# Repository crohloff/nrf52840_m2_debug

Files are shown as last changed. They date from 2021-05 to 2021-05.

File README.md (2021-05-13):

# nrf52840_m2_debug
Debug board for the M.2 module

## features
- access to all pins
- 4 buttons
- 4 LEDs
- USB-C connectivity
- TC2030 debug connector

## dimensions
- 60mm x 90mm

## board front
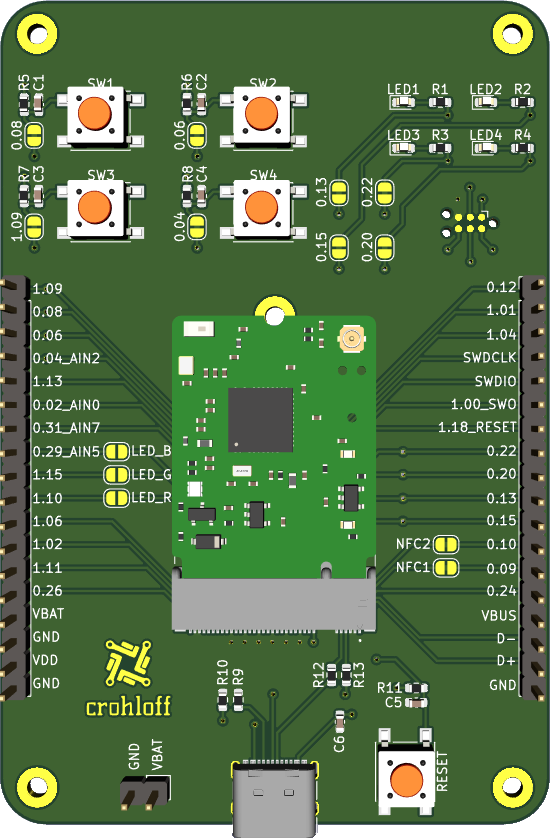
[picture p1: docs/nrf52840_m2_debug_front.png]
board front


## board back
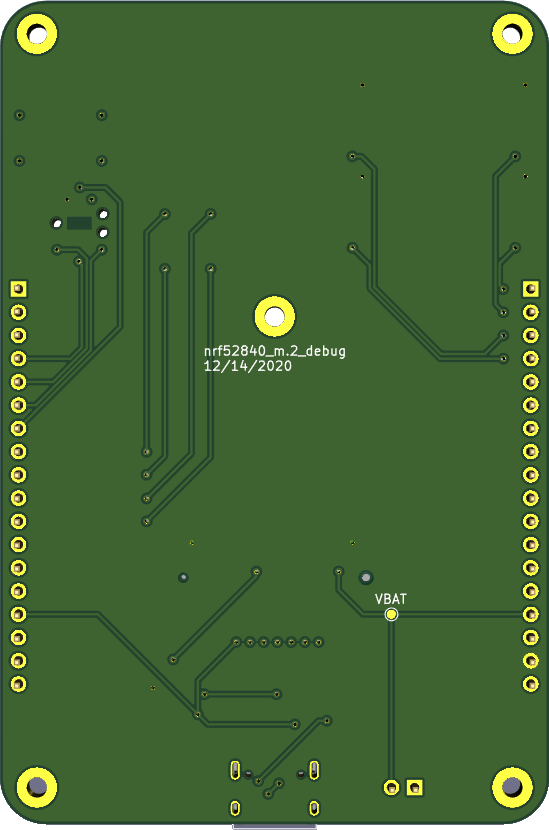
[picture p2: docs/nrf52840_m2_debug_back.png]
board back


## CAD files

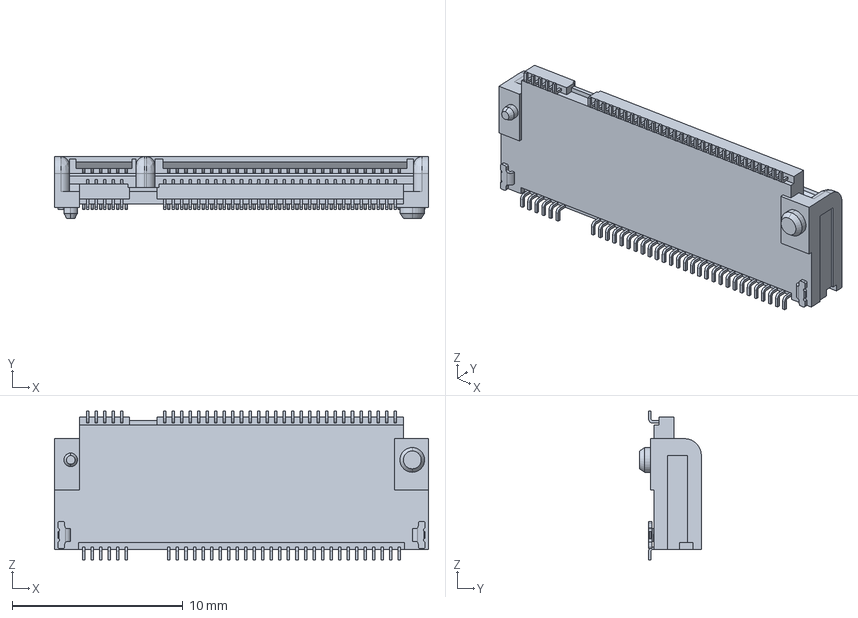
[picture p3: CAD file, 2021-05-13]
custom_3d/te_connectivity_121991190.stp
21.9 x 3.62 x 8.70 mm

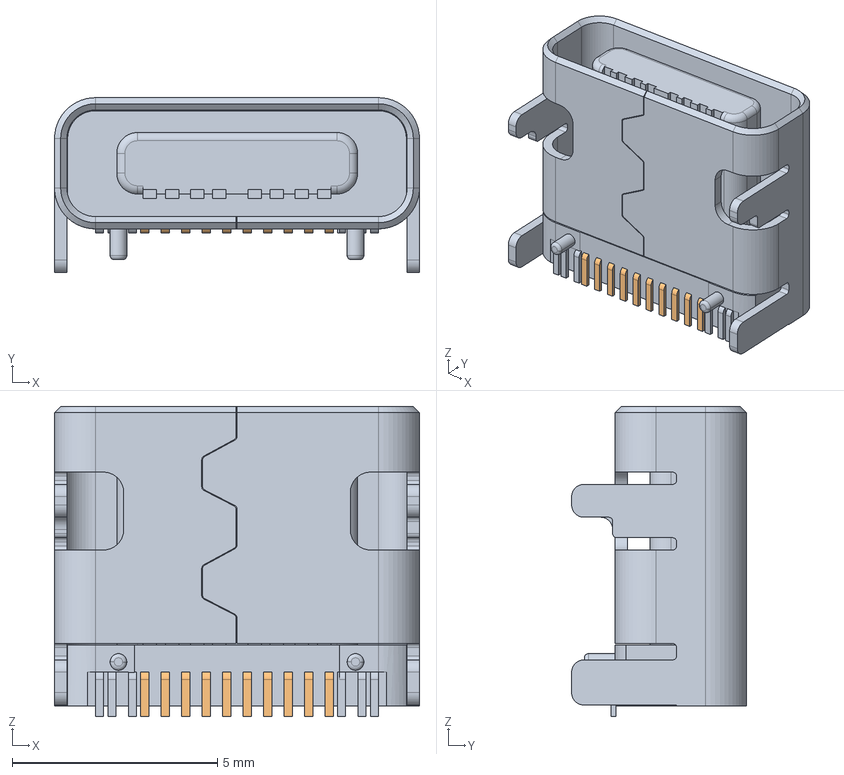
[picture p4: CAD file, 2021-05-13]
custom_3d/XKB_U262-16XN-4BVC11.stp
8.90 x 4.26 x 7.56 mm

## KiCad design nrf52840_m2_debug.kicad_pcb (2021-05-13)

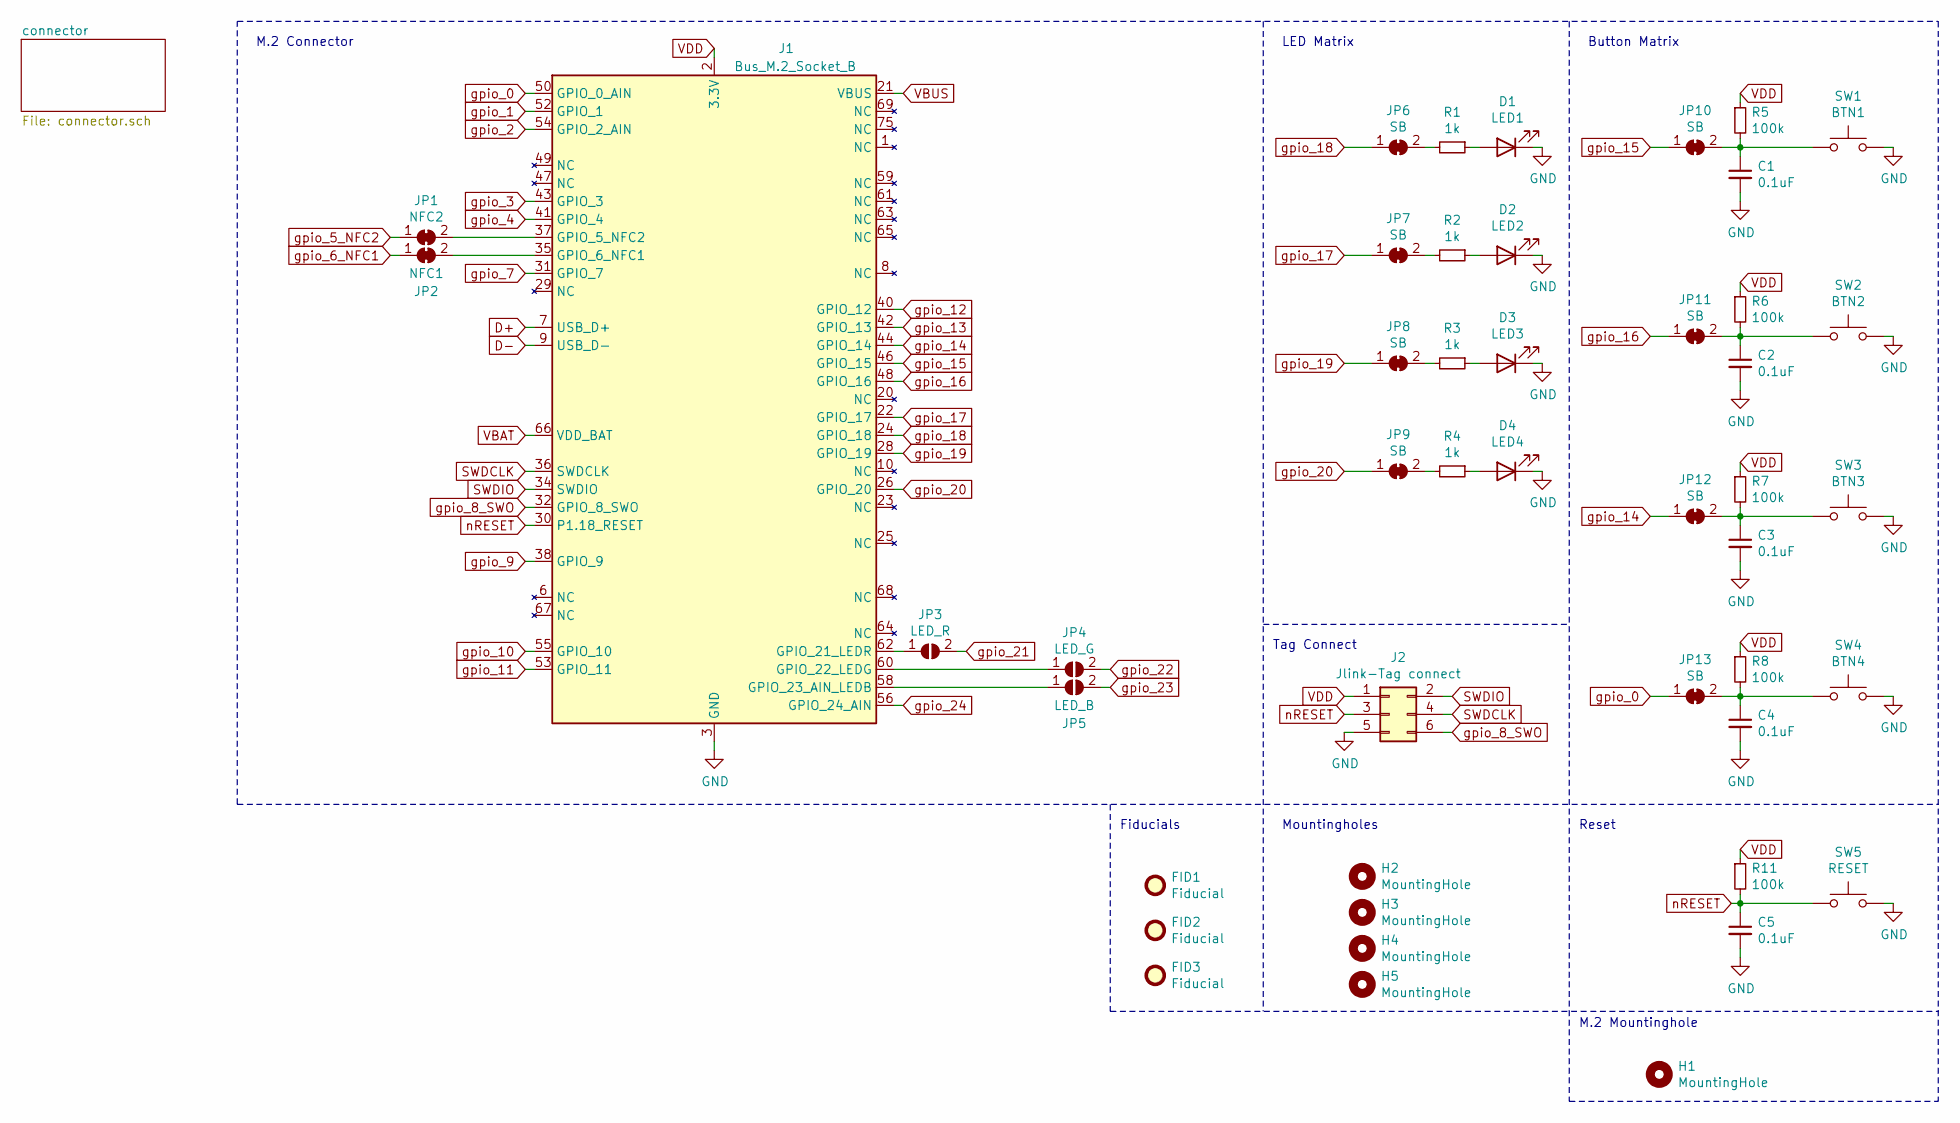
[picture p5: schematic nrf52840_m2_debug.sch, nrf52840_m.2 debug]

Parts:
C1, C2, C3, C4, C5: 0.1uF; C_0603_1608Metric; MFG P/N 063F104Z500CT; LCSC C83060
D1: LED1; LED_0603_1608Metric; MFG P/N LTST-C190KFKT; LCSC C157740
D2: LED2; LED_0603_1608Metric; MFG P/N LTST-C190KFKT; LCSC C157740
D3: LED3; LED_0603_1608Metric; MFG P/N LTST-C190KFKT; LCSC C157740
D4: LED4; LED_0603_1608Metric; MFG P/N LTST-C190KFKT; LCSC C157740
FID1, FID2, FID3: Fiducial; Fiducial_1mm_Mask2mm
H1, H2, H3, H4, H5: MountingHole; MountingHole_2.2mm_M2_Pad
J1: Bus_M.2_Socket_B; te_connectivity_121991190; MFG P/N 2199119; Mouser 571-1-2199119-0
J2: Jlink-Tag connect; Tag-Connect_TC2030-IDC-NL_2x03_P1.27mm_Vertical
JP1: NFC2; SolderJumper-2_P1.3mm_Bridged_RoundedPad1.0x1.5mm
JP2: NFC1; SolderJumper-2_P1.3mm_Bridged_RoundedPad1.0x1.5mm
JP3: LED_R; SolderJumper-2_P1.3mm_Open_RoundedPad1.0x1.5mm
JP4: LED_G; SolderJumper-2_P1.3mm_Open_RoundedPad1.0x1.5mm
JP5: LED_B; SolderJumper-2_P1.3mm_Open_RoundedPad1.0x1.5mm
JP6, JP7, JP8, JP9, JP10, JP11, JP12, JP13: SB; SolderJumper-2_P1.3mm_Bridged_RoundedPad1.0x1.5mm
R1, R2, R3, R4: 1k; R_0603_1608Metric; MFG P/N RC0603JR-071KL; LCSC C14676
R5, R6, R7, R8, R11: 100k; R_0603_1608Metric; MFG P/N RC0603JR-07100KL; LCSC C100048
SW1: BTN1; SW_SPST_PTS645; MFG P/N PTS645SH43SMTR92LFS; LCSC C285463
SW2: BTN2; SW_SPST_PTS645; MFG P/N PTS645SH43SMTR92LFS; LCSC C285463
SW3: BTN3; SW_SPST_PTS645; MFG P/N PTS645SH43SMTR92LFS; LCSC C285463
SW4: BTN4; SW_SPST_PTS645; MFG P/N PTS645SH43SMTR92LFS; LCSC C285463
SW5: RESET; SW_SPST_PTS645; MFG P/N PTS645SH43SMTR92LFS; LCSC C285463

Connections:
D+: J1.7 (USB_D+); also elsewhere on the board
D-: J1.9 (USB_D-); also elsewhere on the board
GND: C1.2, C2.2, C3.2, C4.2, C5.2, D1.1 (K), D2.1 (K), D3.1 (K), D4.1 (K), J1.3 (GND), J1.5 (GND), J1.11 (GND), J1.27 (GND), J1.33 (GND), J1.39 (GND), J1.45 (GND), J1.51 (GND), J1.57 (GND), J1.71 (GND), J1.73 (GND), J2.5, SW1.2, SW2.2, SW3.2, SW4.2, SW5.2; also elsewhere on the board
unnamed: C1.1, JP10.2 (B), R5.2, SW1.1
unnamed: C2.1, JP11.2 (B), R6.2, SW2.1
unnamed: C3.1, JP12.2 (B), R7.2, SW3.1
unnamed: C4.1, JP13.2 (B), R8.2, SW4.1
unnamed: D1.2 (A), R1.1
unnamed: D2.2 (A), R2.1
unnamed: D3.2 (A), R3.1
unnamed: D4.2 (A), R4.1
unnamed: J1.35 (GPIO_6_NFC1), JP2.2 (B)
unnamed: J1.37 (GPIO_5_NFC2), JP1.2 (B)
unnamed: J1.58 (GPIO_23_AIN_LEDB), JP5.1 (A)
unnamed: J1.60 (GPIO_22_LEDG), JP4.1 (A)
unnamed: J1.62 (GPIO_21_LEDR), JP3.1 (A)
unnamed: JP6.2 (B), R1.2
unnamed: JP7.2 (B), R2.2
unnamed: JP8.2 (B), R3.2
unnamed: JP9.2 (B), R4.2
SWDCLK: J1.36 (SWDCLK), J2.4; also elsewhere on the board
SWDIO: J1.34 (SWDIO), J2.2; also elsewhere on the board
VBAT: J1.66 (VDD_BAT); also elsewhere on the board
VBUS: J1.21 (VBUS); also elsewhere on the board
VDD: J1.2 (3.3V), J1.4 (3.3V), J1.70 (3.3V), J1.72 (3.3V), J1.74 (3.3V), J2.1, R5.1, R6.1, R7.1, R8.1, R11.1; also elsewhere on the board
gpio_0: J1.50 (GPIO_0_AIN), JP13.1 (A); also elsewhere on the board
gpio_1: J1.52 (GPIO_1); also elsewhere on the board
gpio_2: J1.54 (GPIO_2_AIN); also elsewhere on the board
gpio_3: J1.43 (GPIO_3); also elsewhere on the board
gpio_4: J1.41 (GPIO_4); also elsewhere on the board
gpio_5_NFC2: JP1.1 (A); also elsewhere on the board
gpio_6_NFC1: JP2.1 (A); also elsewhere on the board
gpio_7: J1.31 (GPIO_7); also elsewhere on the board
gpio_8_SWO: J1.32 (GPIO_8_SWO), J2.6; also elsewhere on the board
gpio_9: J1.38 (GPIO_9); also elsewhere on the board
gpio_10: J1.55 (GPIO_10); also elsewhere on the board
gpio_11: J1.53 (GPIO_11); also elsewhere on the board
gpio_12: J1.40 (GPIO_12); also elsewhere on the board
gpio_13: J1.42 (GPIO_13); also elsewhere on the board
gpio_14: J1.44 (GPIO_14), JP12.1 (A); also elsewhere on the board
gpio_15: J1.46 (GPIO_15), JP10.1 (A); also elsewhere on the board
gpio_16: J1.48 (GPIO_16), JP11.1 (A); also elsewhere on the board
gpio_17: J1.22 (GPIO_17), JP7.1 (A); also elsewhere on the board
gpio_18: J1.24 (GPIO_18), JP6.1 (A); also elsewhere on the board
gpio_19: J1.28 (GPIO_19), JP8.1 (A); also elsewhere on the board
gpio_20: J1.26 (GPIO_20), JP9.1 (A); also elsewhere on the board
gpio_21: JP3.2 (B); also elsewhere on the board
gpio_22: JP4.2 (B); also elsewhere on the board
gpio_23: JP5.2 (B); also elsewhere on the board
gpio_24: J1.56 (GPIO_24_AIN); also elsewhere on the board
nRESET: C5.1, J1.30 (P1.18_RESET), J2.3, R11.2, SW5.1; also elsewhere on the board

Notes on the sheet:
LED Matrix
Button Matrix
Reset
Mountingholes
M.2 Mountinghole
Tag Connect
M.2 Connector
Fiducials

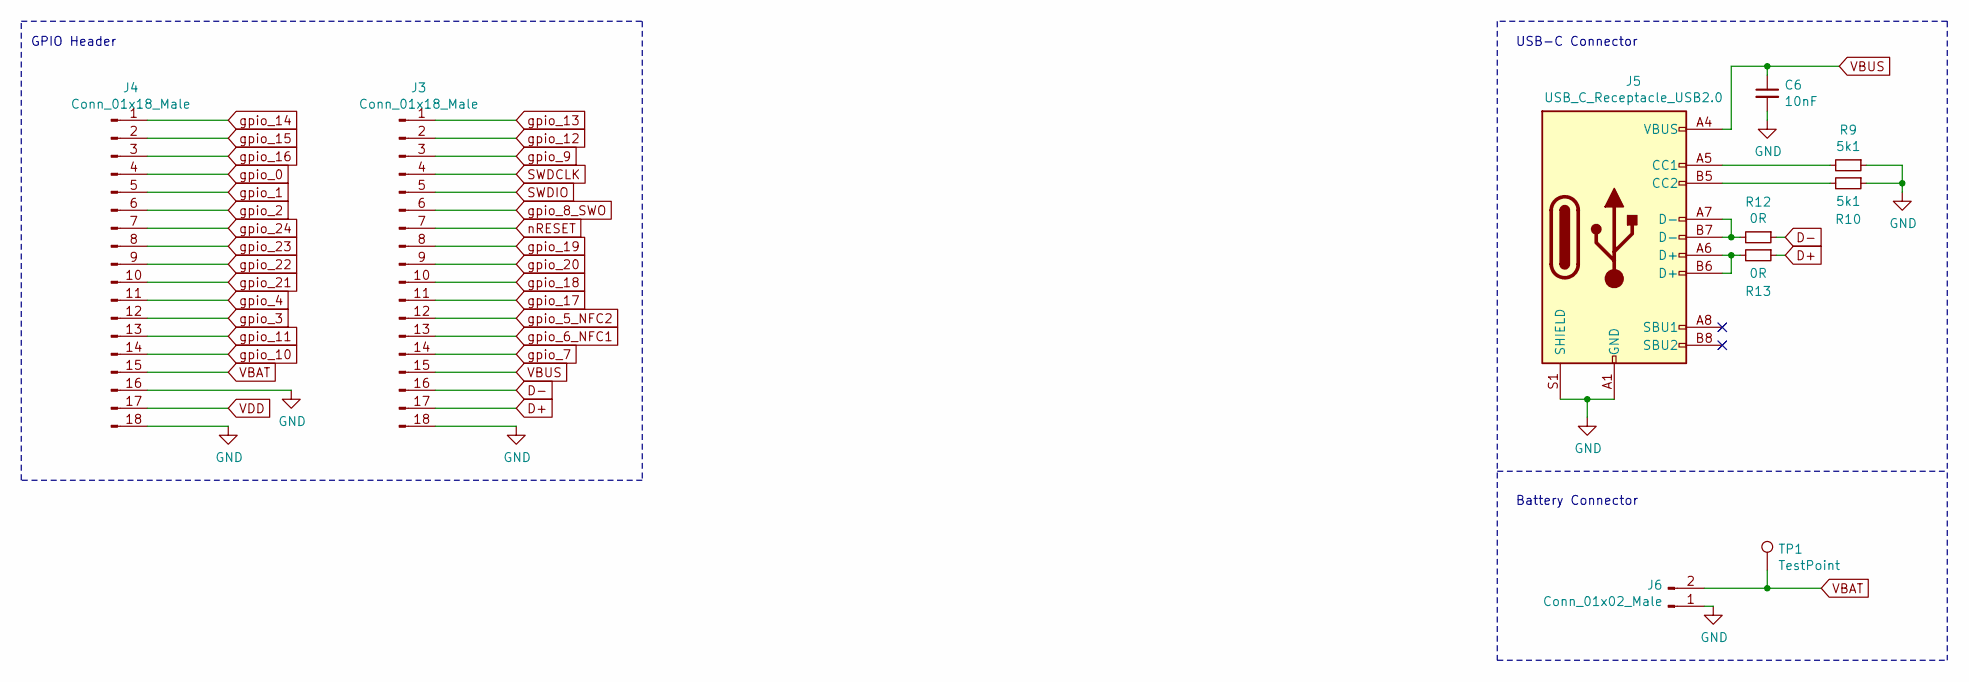
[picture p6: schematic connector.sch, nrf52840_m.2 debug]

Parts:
C6: 10nF; C_0603_1608Metric; MFG P/N CC0603KRX7R9BB103; LCSC C100042
J3, J4: Conn_01x18_Male; PinHeader_1x18_P2.54mm_Vertical; MFG P/N MTP125-1104S1; LCSC C358686
J5: USB_C_Receptacle_USB2.0; USB_C_Receptacle_XKB_U262-16XN-4BVC11; MFG P/N U262-161N-4BVC11; LCSC C319148
J6: Conn_01x02_Male; PinHeader_1x02_P2.54mm_Vertical; MFG P/N 210-91-02GB01; LCSC C390678
R9, R10: 5k1; R_0603_1608Metric; MFG P/N RC0603FR-075K11L; LCSC C112314
R12, R13: 0R; R_0603_1608Metric; MFG P/N RC0603JR-070RL; LCSC C95177
TP1: TestPoint; TestPoint_Pad_D1.0mm

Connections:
D+: J3.17, R13.1; also elsewhere on the board
D-: J3.16, R12.1; also elsewhere on the board
GND: C6.2, J3.18, J4.16, J4.18, J5.A1 (GND), J5.A12 (GND), J5.B1 (GND), J5.B12 (GND), J5.S1 (SHIELD), J6.1, R9.1, R10.1; also elsewhere on the board
unnamed: J5.A5 (CC1), R9.2
unnamed: J5.A6 (D+), J5.B6 (D+), R13.2
unnamed: J5.A7 (D-), J5.B7 (D-), R12.2
unnamed: J5.B5 (CC2), R10.2
SWDCLK: J3.4; also elsewhere on the board
SWDIO: J3.5; also elsewhere on the board
VBAT: J4.15, J6.2, TP1.1; also elsewhere on the board
VBUS: C6.1, J3.15, J5.A4 (VBUS), J5.A9 (VBUS), J5.B4 (VBUS), J5.B9 (VBUS); also elsewhere on the board
VDD: J4.17; also elsewhere on the board
gpio_0: J4.4; also elsewhere on the board
gpio_1: J4.5; also elsewhere on the board
gpio_2: J4.6; also elsewhere on the board
gpio_3: J4.12; also elsewhere on the board
gpio_4: J4.11; also elsewhere on the board
gpio_5_NFC2: J3.12; also elsewhere on the board
gpio_6_NFC1: J3.13; also elsewhere on the board
gpio_7: J3.14; also elsewhere on the board
gpio_8_SWO: J3.6; also elsewhere on the board
gpio_9: J3.3; also elsewhere on the board
gpio_10: J4.14; also elsewhere on the board
gpio_11: J4.13; also elsewhere on the board
gpio_12: J3.2; also elsewhere on the board
gpio_13: J3.1; also elsewhere on the board
gpio_14: J4.1; also elsewhere on the board
gpio_15: J4.2; also elsewhere on the board
gpio_16: J4.3; also elsewhere on the board
gpio_17: J3.11; also elsewhere on the board
gpio_18: J3.10; also elsewhere on the board
gpio_19: J3.8; also elsewhere on the board
gpio_20: J3.9; also elsewhere on the board
gpio_21: J4.10; also elsewhere on the board
gpio_22: J4.9; also elsewhere on the board
gpio_23: J4.8; also elsewhere on the board
gpio_24: J4.7; also elsewhere on the board
nRESET: J3.7; also elsewhere on the board

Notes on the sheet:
GPIO Header
USB-C Connector
Battery Connector

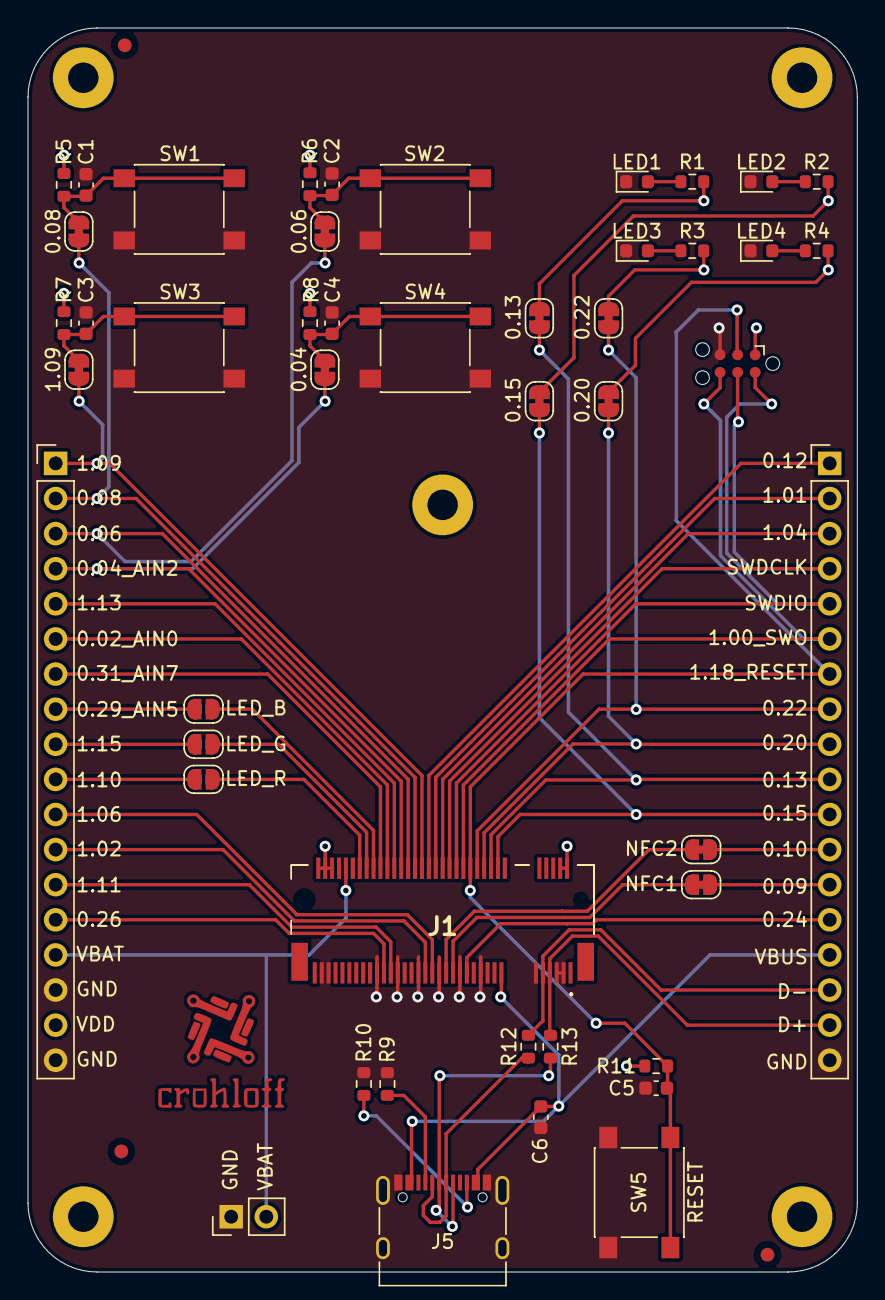
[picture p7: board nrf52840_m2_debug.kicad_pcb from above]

Board: 2 copper layers, 60.0 x 90.0 mm, 56 parts (1 on the bottom side), 55 nets.
